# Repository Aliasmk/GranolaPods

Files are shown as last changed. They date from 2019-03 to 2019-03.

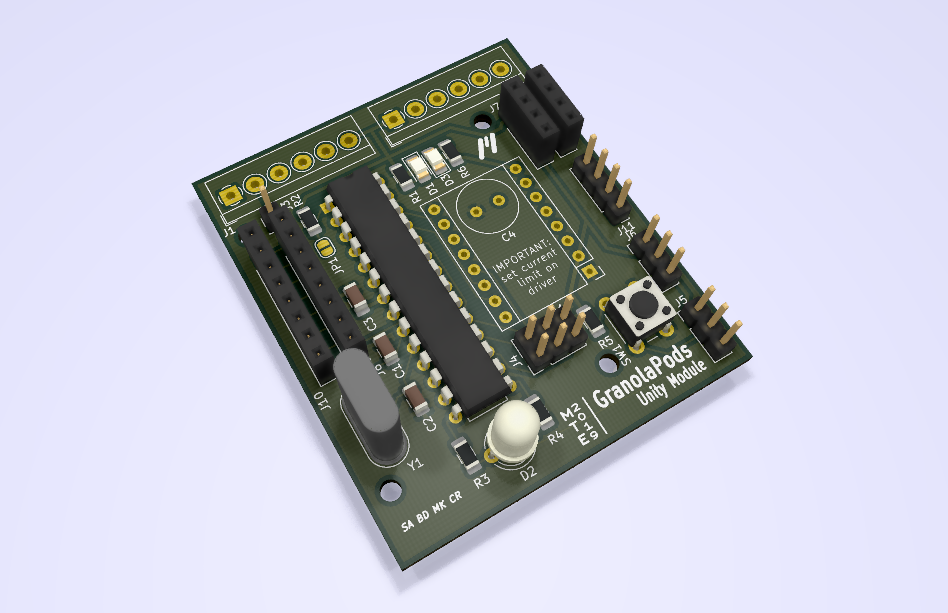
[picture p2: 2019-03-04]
Unity PCB/PCB.png

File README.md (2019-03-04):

# GranolaPods
This repo contains the the frontend website code, the backend server code, as well as the hardware (PCB) and firmware of the GranolaPods modular Unity system.

## About

GranolaPods is an automated trail mix making machine that creates a custom snack based on your personalized macronutrient requirements. Coding and algorithms take your health requirements into account and select ingredients to suit your needs. The end product is a GranolaPod (granola treat with a personality!) served in a convenient and resealable package, perfect for health conscious, on-the-go individuals.

The Unity Module is an I2C-based modular control board for the GranolaPods smart trail-mix making machine. Why the name "Unity"? The board and code is designed to be modular - all devices in the GranolaPods system (e.g. the Gantry Cart, the Dispensers, and any future devices such as mixers or binders) all united on the same bus and using the same PCB and code.

This was developed for University of Waterloo Mechatronics FYDP Team #26.

## How it works

The front end and server are both run locally on a Raspberry Pi. In the GranolaPods system we are using a 7" touchscreen that will display the user interface via a web browser. Submitting a request will generate an HTTP POST, and pass values to the python backend. The backend running on the Pi will sequentially coordinate the Unity modules down the chain to create the snack. Communication between the Pi master and n Unity slaves are done with i2c.

The Unity modules are powered by an ATmega328P. Programming is done through the Arduino IDE via ICSP pins.

## Want to see it in action?

To see how the GranolaPods system was envisioned to work check out [this video](https://www.youtube.com/watch?v=Usi5u81KuWI). Unfortunatly due to time constraints we had to reduce the scope and remove the mixing and binding steps and make trail mix rather than granola bars.

For a demonstration of the Unity system you can check out [this video](https://www.youtube.com/watch?v=NxC_GapGs20).

## Want to (attempt to) run it?

To run the server, simply run ```python ./server/server.py```, then navigate to ```localhost```.

Currently the system will crash if a GranolaPod is requested with no Unity boards attached. It would probably crash even more spectacularly if you tried running it on something other than a Raspberry Pi.

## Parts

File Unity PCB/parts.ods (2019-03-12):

Id | Designator | Package | Quantity | 6xQuantity | Designation | Supplier and ref
1 | A1 | Pololu_Breakout-16_15.2x20.3mm | 1 | 6 | Pololu_Breakout_A4988
2 | C3 | C_1206_3216Metric_Pad1.42x1.75mm_HandSolder | 1 | 6 | 0.1uF
3 | C4 | C_Radial_D8.0mm_H11.5mm_P3.50mm | 1 | 6 | 100uF
4 | D1,D3 | LED_1206_3216Metric_Pad1.42x1.75mm_HandSolder | 2 | 12 | LED
5 | D2 | LED_D5.0mm-3 | 1 | 6 | LED_Dual_AAC
6 | J1,J2 | TerminalBlock_4Ucon_1x06_P3.50mm_Horizontal | 2 | 12 | Screw_Terminal_01x06
7 | J3 | PinHeader_1x01_P2.54mm_Vertical | 1 | 6 | Conn_01x01
8 | J4 | PinHeader_2x03_P2.54mm_Vertical | 1 | 6 | Conn_02x03_Counter_Clockwise
9 | J5,J6 | PinHeader_1x03_P2.54mm_Vertical | 2 | 12 | Conn_01x03
10 | J8 | PinSocket_1x08_P2.54mm_Vertical | 1 | 6 | SIG_HEADER
11 | JP1 | SolderJumper-2_P1.3mm_Open_RoundedPad1.0x1.5mm | 1 | 6 | SolderJumper_2_Open
12 | R1,R3,R4 | R_1206_3216Metric_Pad1.42x1.75mm_HandSolder | 3 | 18 | 860R
13 | R2,R5,R6,R7,R8,R9,R10,R11 | R_1206_3216Metric_Pad1.42x1.75mm_HandSolder | 8 | 48 | 10K
14 | SW1 | SW_PUSH_6mm | 1 | 6 | SW_SPST
15 | U1 | DIP-28_W7.62mm | 1 | 6 | ATmega328P-PU
16 | Y1 | Crystal_HC49-U_Vertical | 1 | 6 | Crystal
17 | J11 | PinHeader_1x04_P2.54mm_Vertical | 1 | 6 | Conn_01x04_Male
18 | J10 | PinSocket_1x08_P2.54mm_Vertical | 1 | 6 | AUX_HEADER
19 | C1,C2 | C_1206_3216Metric | 2 | 12 | 18pF
20 | J7,J9 | PinSocket_1x04_P2.54mm_Vertical | 2 | 12 | Conn_01x04

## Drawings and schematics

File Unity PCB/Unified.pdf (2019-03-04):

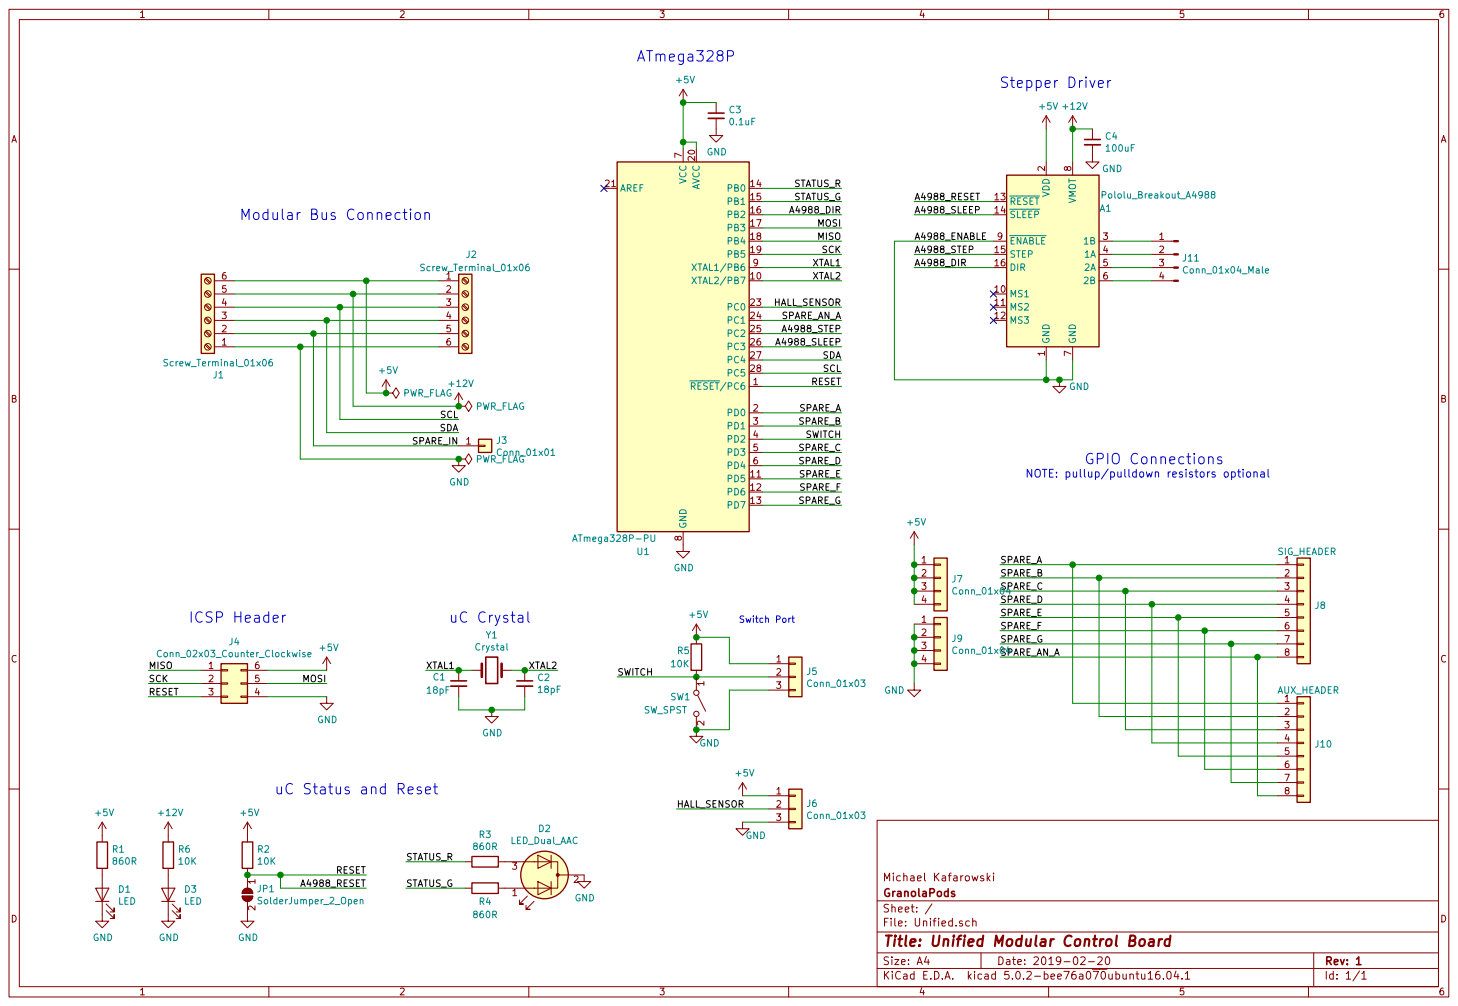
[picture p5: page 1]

8 ENABLE 9 A1Pololu_Breakout_A4988 RESET/PC6 1 XTAL2/PB7 10 PD5 11 PD6 12 PD7 13 PB0 14 PB1 15 PB2 16 PB3 17 PB4 18 PB5 19 PD0 2 AVCC 20 AREF 21 PC0 23 PC1 24 PC2 25 PC3 26 PC4 27 PC5 28 PD1 3 PD2 4 PD3 5 PD4 6 VCC

1 MS1 10 MS2 11 MS3 12 RESET 13 SLEEP 14 STEP 15 DIR 16 VDD

GND Modular Bus Connection

5 | 2 | J2 Screw_Terminal_01x06 +5V

NOTE: pullup/pulldown resistors optional SPARE_AN_A

2 | SPARE_B | 2
3 | SPARE_C | | 3
4 | SPARE_D | | | 4

uC Status and Reset
+5V GND

Id: 1/1 Title: Unified Modular Control Board

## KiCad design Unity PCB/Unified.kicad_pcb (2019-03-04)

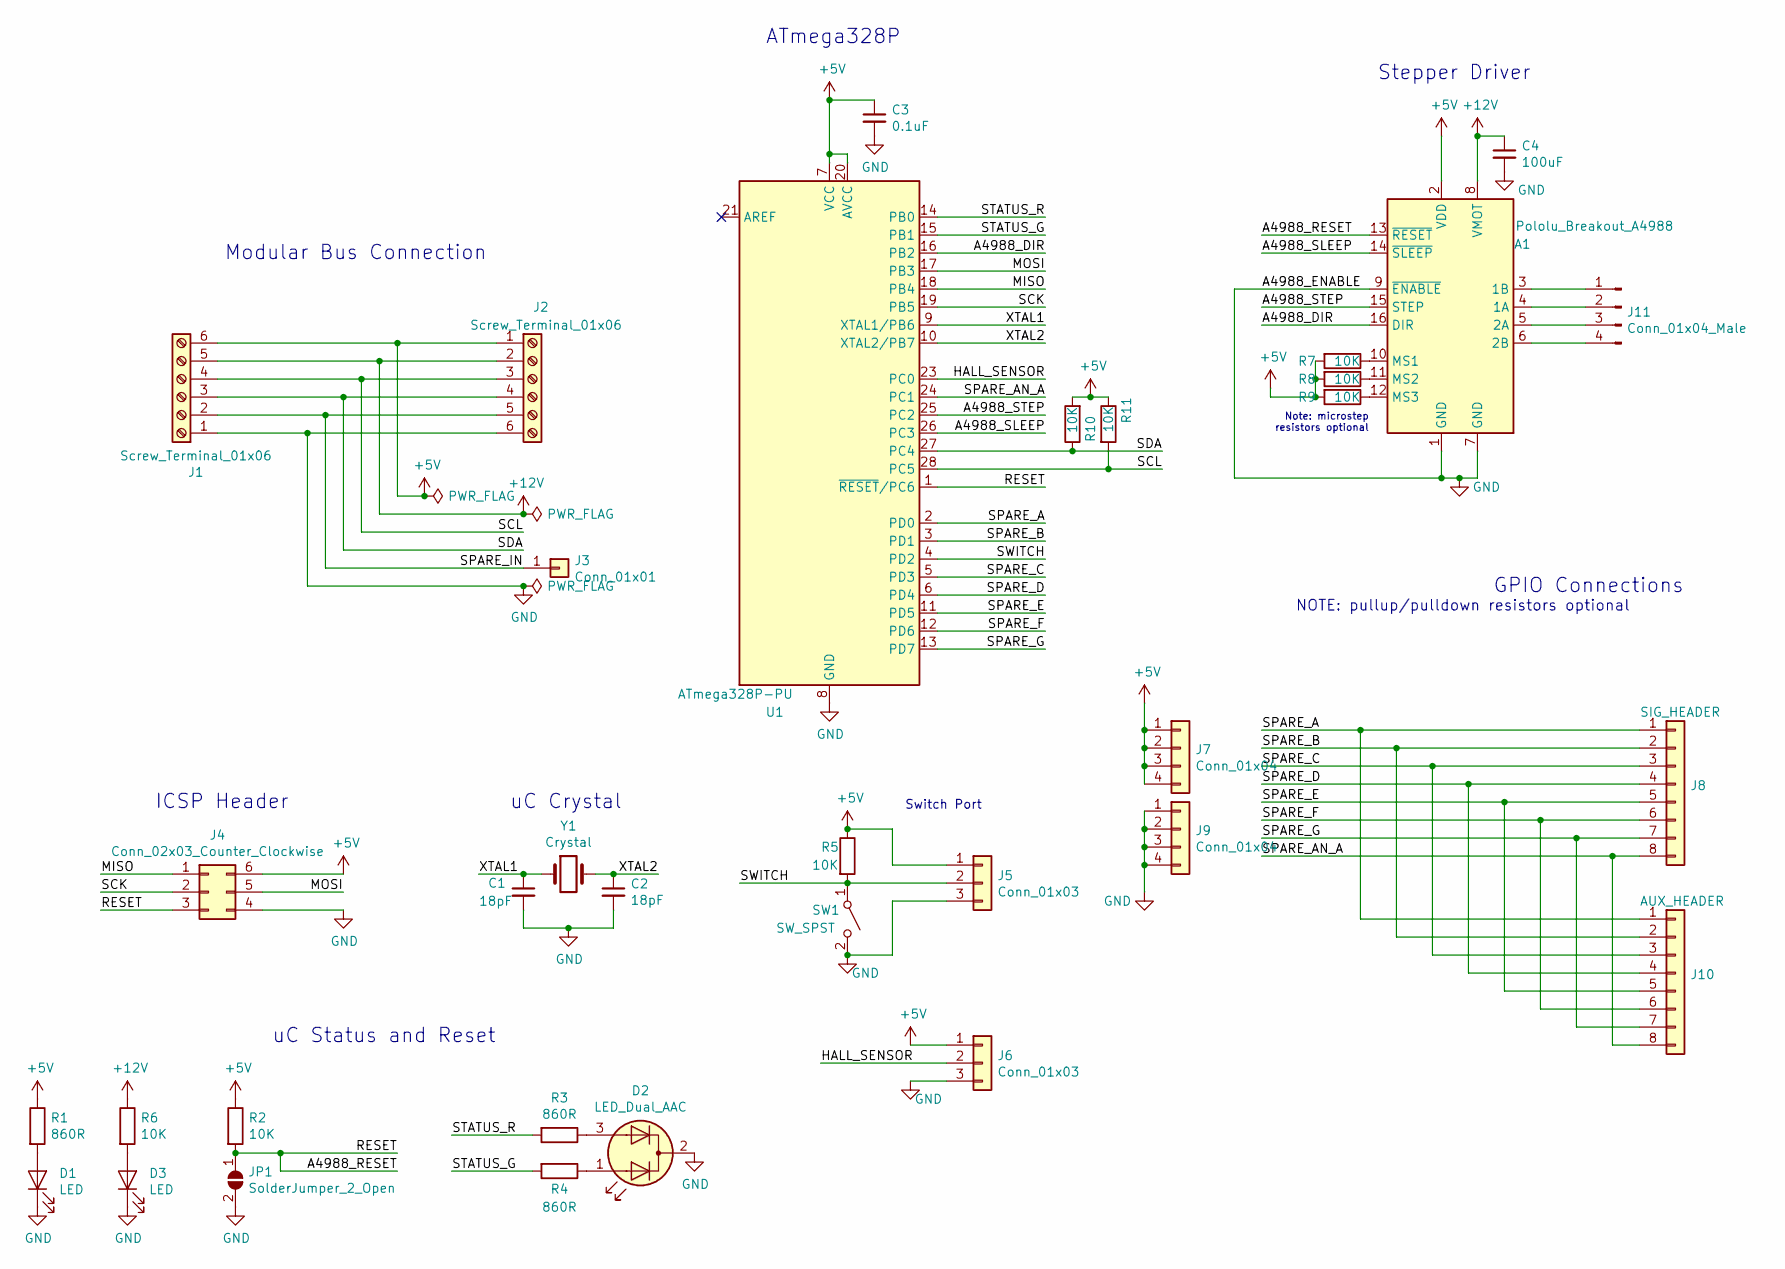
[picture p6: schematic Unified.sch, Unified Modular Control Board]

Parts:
A1: Pololu_Breakout_A4988; Pololu_Breakout-16_15.2x20.3mm
C1, C2: 18pF; C_1206_3216Metric
C3: 0.1uF; C_1206_3216Metric_Pad1.42x1.75mm_HandSolder
C4: 100uF; C_Radial_D8.0mm_H11.5mm_P3.50mm
D1, D3: LED; LED_1206_3216Metric_Pad1.42x1.75mm_HandSolder
D2: LED_Dual_AAC; LED_D5.0mm-3
J1, J2: Screw_Terminal_01x06; TerminalBlock_4Ucon_1x06_P3.50mm_Horizontal
J3: Conn_01x01; PinHeader_1x01_P2.54mm_Vertical
J4: Conn_02x03_Counter_Clockwise; PinHeader_2x03_P2.54mm_Vertical
J5, J6: Conn_01x03; PinHeader_1x03_P2.54mm_Vertical
J7, J9: Conn_01x04; PinSocket_1x04_P2.54mm_Vertical
J8: SIG_HEADER; PinSocket_1x08_P2.54mm_Vertical
J10: AUX_HEADER; PinSocket_1x08_P2.54mm_Vertical
J11: Conn_01x04_Male; PinHeader_1x04_P2.54mm_Vertical
JP1: SolderJumper_2_Open; SolderJumper-2_P1.3mm_Open_RoundedPad1.0x1.5mm
R1, R3, R4: 860R; R_1206_3216Metric_Pad1.42x1.75mm_HandSolder
R2, R5, R6, R7, R8, R9, R10, R11: 10K; R_1206_3216Metric_Pad1.42x1.75mm_HandSolder
SW1: SW_SPST; SW_PUSH_6mm
U1: ATmega328P-PU; DIP-28_W7.62mm
Y1: Crystal; Crystal_HC49-U_Vertical

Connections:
+5V: A1.2 (VDD), C3.1, J1.6, J2.1, J4.6, J5.1, J6.1, J7.1, J7.2, J7.3, J7.4, R1.1, R2.1, R5.1, R7.2, R8.2, R9.2, R10.2, R11.1, U1.7 (VCC), U1.20 (AVCC)
+12V: A1.8 (VMOT), C4.1, J1.5, J2.2, R6.1
/A4988_DIR: A1.16 (DIR), U1.16 (PB2)
/A4988_RESET: A1.13 (~RESET), J4.3, JP1.1 (A), R2.2, U1.1 (~RESET~/PC6)
/A4988_SLEEP: A1.14 (~SLEEP), U1.26 (PC3)
/A4988_STEP: A1.15 (STEP), U1.25 (PC2)
/HALL_SENSOR: J6.2, U1.23 (PC0)
/MISO: J4.1, U1.18 (PB4)
/MOSI: J4.5, U1.17 (PB3)
/SCK: J4.2, U1.19 (PB5)
/SCL: J1.4, J2.3, R11.2, U1.28 (PC5)
/SDA: J1.3, J2.4, R10.1, U1.27 (PC4)
/SPARE_A: J8.1, J10.1, U1.2 (PD0)
/SPARE_AN_A: J8.8, J10.8, U1.24 (PC1)
/SPARE_B: J8.2, J10.2, U1.3 (PD1)
/SPARE_C: J8.3, J10.3, U1.5 (PD3)
/SPARE_D: J8.4, J10.4, U1.6 (PD4)
/SPARE_E: J8.5, J10.5, U1.11 (PD5)
/SPARE_F: J8.6, J10.6, U1.12 (PD6)
/SPARE_G: J8.7, J10.7, U1.13 (PD7)
/SPARE_IN: J1.2, J2.5, J3.1
/STATUS_G: R4.2, U1.15 (PB1)
/STATUS_R: R3.2, U1.14 (PB0)
/SWITCH: J5.2, R5.2, SW1.1 (A), U1.4 (PD2)
/XTAL1: C1.1, U1.9 (XTAL1/PB6), Y1.1
/XTAL2: C2.1, U1.10 (XTAL2/PB7), Y1.2
GND: A1.1 (GND), A1.7 (GND), A1.9 (~ENABLE), C1.2, C2.2, C3.2, C4.2, D1.1 (K), D2.2 (K), D3.1 (K), J1.1, J2.6, J4.4, J5.3, J6.3, J9.1, J9.2, J9.3, J9.4, JP1.2 (B), SW1.2 (B), U1.8 (GND), U1.22 (GND)
unnamed: A1.3 (1B), J11.1
unnamed: A1.4 (1A), J11.2
unnamed: A1.5 (2A), J11.3
unnamed: A1.6 (2B), J11.4
unnamed: A1.10 (MS1), R7.1
unnamed: A1.11 (MS2), R8.1
unnamed: A1.12 (MS3), R9.1
unnamed: D1.2 (A), R1.2
unnamed: D2.1 (A1), R4.1
unnamed: D2.3 (A2), R3.1
unnamed: D3.2 (A), R6.2

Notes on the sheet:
Modular Bus Connection
ICSP Header
uC Status and Reset
uC Crystal
Switch Port
Stepper Driver
ATmega328P
GPIO Connections
NOTE: pullup/pulldown resistors optional
Note: microstep resistors optional

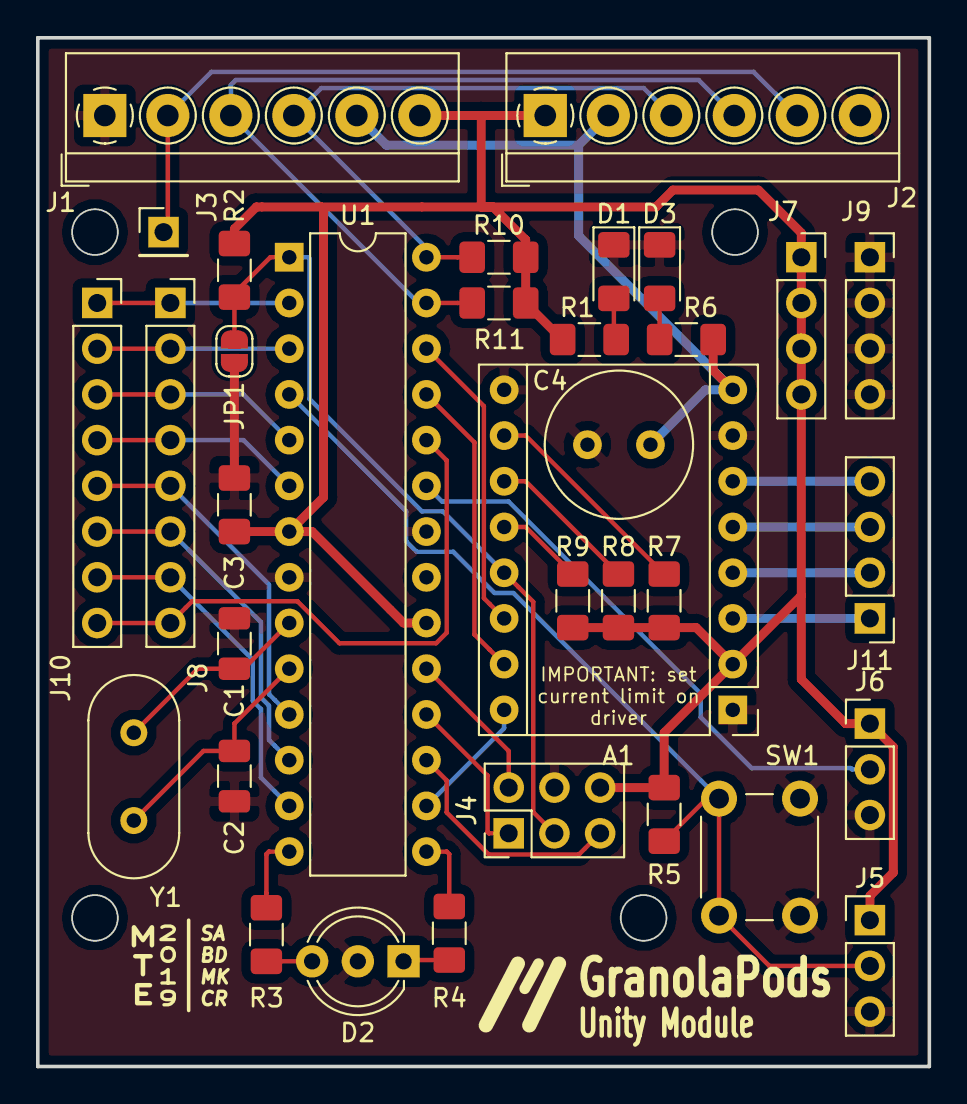
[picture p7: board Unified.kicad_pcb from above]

Board: 2 copper layers, 49.5 x 57.1 mm, 34 parts (0 on the bottom side), 38 nets.

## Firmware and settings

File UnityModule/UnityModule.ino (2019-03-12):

#include <Arduino.h>
#include <Wire.h>
#include <Servo.h>

Servo cupdisp;

#define I2C_ADDRESS 0x4
#define MICROSTEPS 1
#define HALL_SENSOR A0

volatile int state = 0;                  //States are general machine states
#define STATE_STOPPED 0
#define STATE_MOVING 1
#define STATE_SWITCHPOLLING 2
#define STATE_SWITCHTRIGGER 3
#define STATE_HALLPOLLING 4
#define STATE_HALLTRIGGER 5



//General Pin Definitions
#define LIMIT_SWITCH 2
#define STATUS_G 8
#define STATUS_R 9
 
#define STEPPER_DIR 10
#define STEPPER_STEP 16
#define STEPPER_SLEEP 17
#define CW LOW
#define CCW HIGH
#define STEP_PER_REV 200

volatile bool stepperStatus = false;
volatile long int lastStepAt;
volatile int currentSpeed = 0;
volatile int targetSpeed = 0;

volatile int i2c_data_ready = false;
volatile int i2c_data_request = false;
volatile byte command[5];               //All I2C commands recieved from the Pi are [registerpointer, command, arg1, arg2, arg3].
volatile byte reply[4];

volatile bool hallSensorTriggered = false;
volatile bool switchTriggered = false;
volatile bool cupDispenseReady = false;

void setup() {
  Serial.begin(9600);
  Serial.println("Beginning Startup...");
  
  //Pin Setup
  pinMode(STATUS_G, OUTPUT);
  pinMode(STATUS_R, OUTPUT);
  pinMode(LIMIT_SWITCH, INPUT_PULLUP);
  attachInterrupt(digitalPinToInterrupt(LIMIT_SWITCH), hitLimitSwitch, FALLING);
  Serial.println("Pins Initialized"); 
  
  //Timer Setup for ~200uS
  //TCCR2B = (TCCR2B & B11111000) | 0x02; //Timer2 - 8 divisor
  //TIMSK2 = (TIMSK2 & B11111110) | 0x01; //Enable Timer2 interrupt
  Serial.println("Timer Initialized");
  
  setupStepper();
  Serial.println("Stepper Initialized");
  setupServo();
  Serial.println("Servo Initialized");
  setupI2C();
  Serial.println("I2C Initialized");

  Serial.println("Setup complete");
  setState(STATE_STOPPED);
}


//Timer2 Interrupt (128us)
/*ISR(TIMER2_OVF_vect){
  processMovement();
}*/

/* Main Loop */
void loop() {
  updateStatusIndicator();
  
  #ifdef HALL_SENSOR
   int hallValue = readHallSensor();
  #endif

  if(millis()%2000 == 0){
    Serial.print("Heartbeat. Hall value: ");
    Serial.print(hallValue);
    Serial.print(" (");
    Serial.print(hallSensorTriggered,DEC);
    Serial.println(")");
    
  }

  if(cupDispenseReady){
    dispenseCup();
    cupDispenseReady = false;
  }

  if(i2c_data_ready){
    processI2C();
    i2c_data_ready = false;
  }

  if(i2c_data_request){
    sendI2CReply();
    i2c_data_request = false;
  }

  processMovement();
}

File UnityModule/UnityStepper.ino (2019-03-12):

void setupStepper(){
  //Stepper Motor Setup
  pinMode(STEPPER_DIR, OUTPUT);
  pinMode(STEPPER_STEP, OUTPUT);
  pinMode(STEPPER_SLEEP, OUTPUT);

  stepperStart(60);
  delay(200);
  stepperStop();
  delay(100);
  stepperStart(-60);
  delay(200);
  stepperStop();
  delay(100);

  stepperDisable();
}

void processMovement(){
  if(stepperStatus && micros() - lastStepAt > RPMtoStepDelay(currentSpeed)){
    stepperStep();
  } 
}

//Convert an RPM to step delay in uS. 
long int RPMtoStepDelay(double RPM){
  RPM = max(abs(RPM), 2);
  double result = 300000.0/(double)(RPM*MICROSTEPS);
  return (long int)result;
  //300000uS per step for 200step/rev TODO parametric 
}

//Start the stepper motor motion. 
void stepperStart(int stepperRPM){
  stepperEnable();
  targetSpeed = stepperRPM;
}

//Decel stepper to stop
void stepperStop(){
  targetSpeed = 0; 
}

//Perform one step of the stepper. Also accel or decel to target speed.
void stepperStep(){  
  lastStepAt = micros();   //Update the previous step time

 double Kp = 0.2;
 currentSpeed = round(currentSpeed + Kp*(targetSpeed-currentSpeed));
 
 if(currentSpeed < 0)
    digitalWrite(STEPPER_DIR,CW);
  else if(currentSpeed > 0)
    digitalWrite(STEPPER_DIR,CCW);

  digitalWrite(STEPPER_STEP,HIGH);    //Make step
  digitalWrite(STEPPER_STEP,LOW);

  if(targetSpeed == 0 && abs(currentSpeed) < 10)
    stepperDisable();   //Disable if stopped
}

//Wake up the stepper motor driver
void stepperEnable(){
  if(!stepperStatus){
    //Wake up the stepper driver before stepping
    digitalWrite(STEPPER_SLEEP,HIGH);
    //delay(1); //delay 1ms to allow charge pump to stabilize
    stepperStatus = true;
  }
}

//Put the stepper motor driver to sleep
void stepperDisable(){
  currentSpeed = 0;
  digitalWrite(STEPPER_SLEEP,LOW);
  stepperStatus = false;
  //delay(1);
}

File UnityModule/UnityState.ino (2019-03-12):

//Sets the machine state
void setState(int newState){
  digitalWrite(STATUS_G,LOW);
  digitalWrite(STATUS_R,LOW);
  state = newState;
}

//Asynchronously updates the LED Indicator
void updateStatusIndicator(){
  long int frame = millis();
  
  switch(state){
    case STATE_STOPPED:                 //Stopped: Quick Green Flash
      if(frame%2000 < 50)
        digitalWrite(STATUS_G,HIGH);
      else
        digitalWrite(STATUS_G,LOW);
    break;
    case STATE_MOVING:                  //Moving: Flash Green
      if(frame%1000 < 500)
        digitalWrite(STATUS_G,HIGH);
      else
        digitalWrite(STATUS_G,LOW);
    break; 
      
    case STATE_HALLPOLLING:             //Hall Poll: Red/Green Alternate
      if(frame%500 < 250){
        digitalWrite(STATUS_G,LOW);
        digitalWrite(STATUS_R,HIGH);
      } else {
        digitalWrite(STATUS_G,HIGH);
        digitalWrite(STATUS_R,LOW);
      }
    break;
    case STATE_HALLTRIGGER:             //Hall Trigger: Solid Green
        digitalWrite(STATUS_G,HIGH);
        digitalWrite(STATUS_R,LOW);
    break;
    
    case STATE_SWITCHPOLLING:           //Switch Poll: Flash Red
      if(frame%1000 < 500)
        digitalWrite(STATUS_R,HIGH);
      else
        digitalWrite(STATUS_R,LOW);
    break;
    case STATE_SWITCHTRIGGER:           //Switch Trigger: Solid Red
      digitalWrite(STATUS_R,HIGH);
      digitalWrite(STATUS_G,LOW);
    break;

  }
}

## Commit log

2019-03-04 Fix image of PCB
2019-03-12 Create gerbers, refactor unity code
    [Unified-B.Cu.gbr, Unified-B.Mask.gbr, Unified-B.Paste.gbr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]
2019-03-12 Fixed major issues with i2c. Eliminated timer interrupts for stepper.
    [UnityComm.ino, UnityModule.ino, UnityStepper.ino]
